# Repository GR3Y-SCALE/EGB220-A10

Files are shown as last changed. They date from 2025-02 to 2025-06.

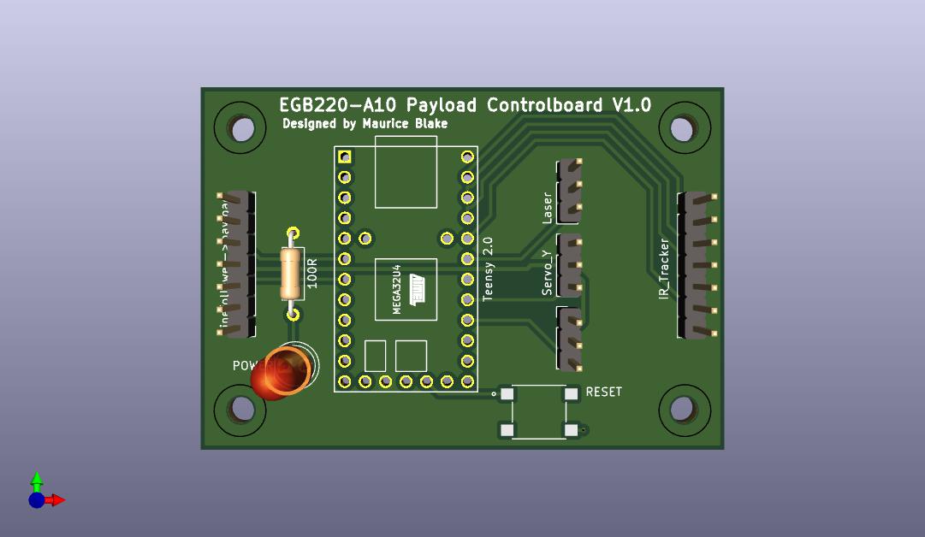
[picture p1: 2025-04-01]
images/PCBs/payload_controlboard_V1.jpg

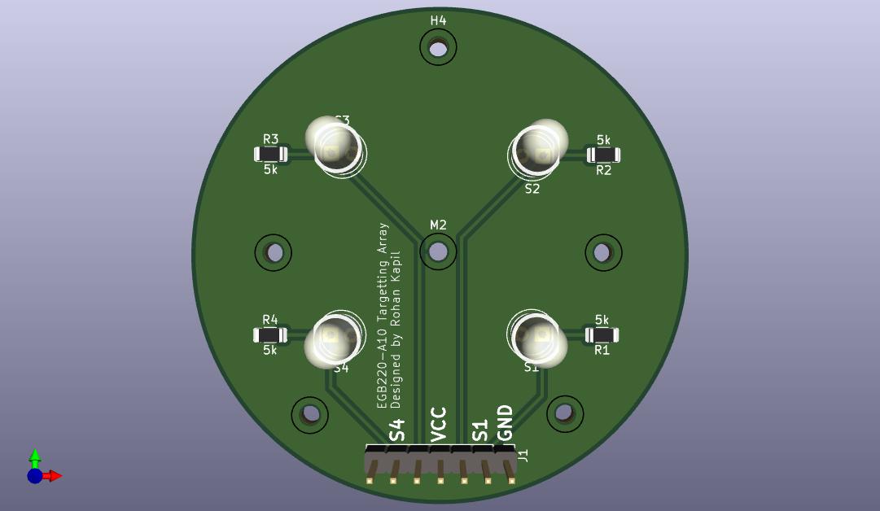
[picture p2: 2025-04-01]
images/PCBs/TargettingPayload.jpg

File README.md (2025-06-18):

# EGB220-A10 - Line follower robot
Robot
General repository for CAD models, PCB design and firmware.

## What is the directory structure?
The initial version of this github repository has several directories that contain relevant readmes similar to this one you are reading right now, they give an example of what goes into that directory.

## Questions?
Feel free to reach out to myself or other the other project members for details and clairifcation.

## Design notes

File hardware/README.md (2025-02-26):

## This directory is for everything related to CAD, such as PCB design and BOMs and 3D models and acrylic cut out files for the line following robot.

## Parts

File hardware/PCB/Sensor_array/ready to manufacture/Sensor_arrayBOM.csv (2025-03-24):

Reference | Value | Datasheet | Footprint | Qty | DNP | DigiKeyPartNumber
C1 | 0.1uF | ~ | Capacitor_SMD:C_0805_2012Metric | 1 |  | 478-KGM21NR71H104KTTR-ND
C2 | 1.0uF | ~ | Capacitor_SMD:C_0805_2012Metric | 1 |  | 1276-1029-2-ND
J2 | 8x2 Sensor Connector | ~ | Connector_PinHeader_2.54mm:PinHeader_2x08_P2.54mm_Vertical | 1
Q1 | BSS214NW | https://www.infineon.com/dgdl/Infineon-BSS214NW-DS-v02_02-en.pdf?fileId=db3a30431b3e89eb011b695aebc01bde | Package_TO_SOT_SMD:SOT-323_SC-70 | 1 |  | QRE1113GRTR-ND
R1,R2,R3,R4,R14,R15 | 47R | ~ | Resistor_SMD:R_0805_2012Metric | 6 |  | RMCF0805JT47R0TR-ND
R5,R6,R7,R8,R9,R10,R11,R12,R13 | 47k | ~ | Resistor_SMD:R_0805_2012Metric | 9 |  | RMCF0805JT47K0TR-ND
U1,U2,U3,U6,U7,U8,U9,U10 | QRE1113GR | http://www.onsemi.com/pub/Collateral/QRE1113-D.PDF | OptoDevice:OnSemi_CASE100CY | 8

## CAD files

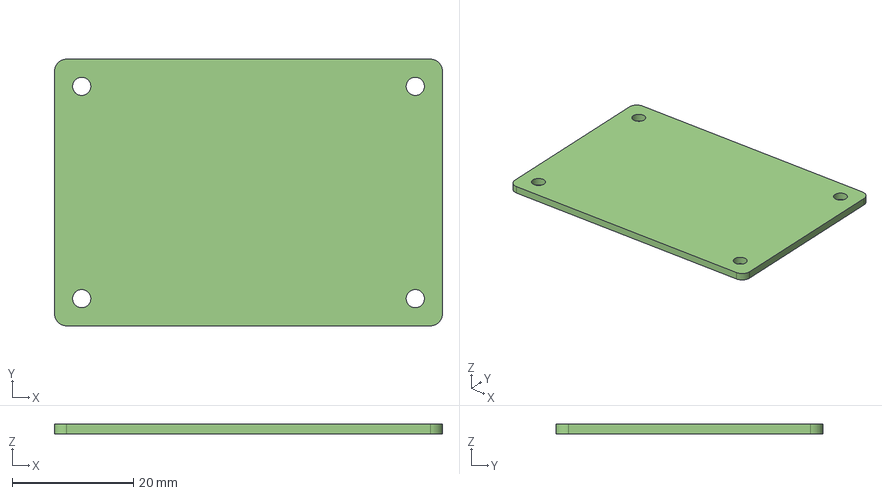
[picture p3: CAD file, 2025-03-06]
hardware/CAD/mvp stage 1/line-follower - mainboard PCB.step
64.0 x 44.0 x 1.60 mm

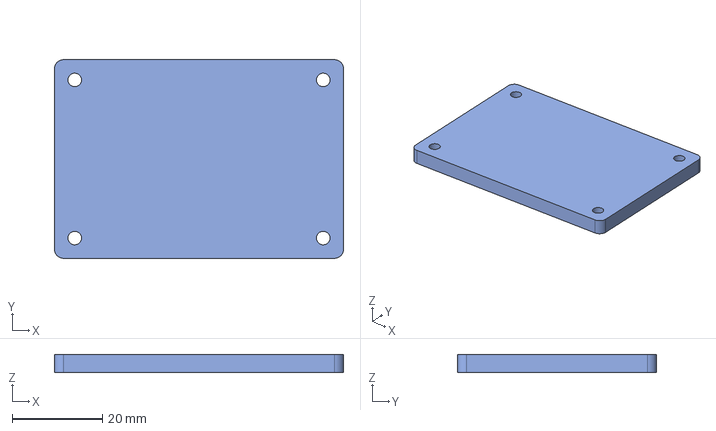
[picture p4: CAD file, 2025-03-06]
hardware/CAD/mvp stage 1/line-follower - PayloadTopPlate.step
64.0 x 44.0 x 4.00 mm

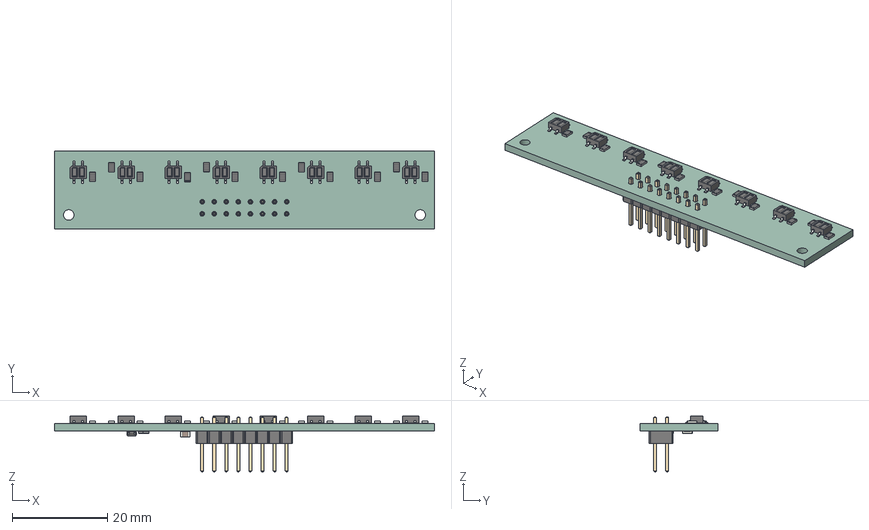
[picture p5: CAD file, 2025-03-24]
hardware/PCB/Sensor_array/ready to manufacture/Sensor_array.step
80.0 x 16.5 x 11.7 mm
R_0805_2012Metric x 15
OnSemi_CASE100CY x 8
C_0805_2012Metric x 2
SOT_323_SC_70
PinHeader_2x08_P254mm_Vertical
_autosave-Sensor_array_PCB

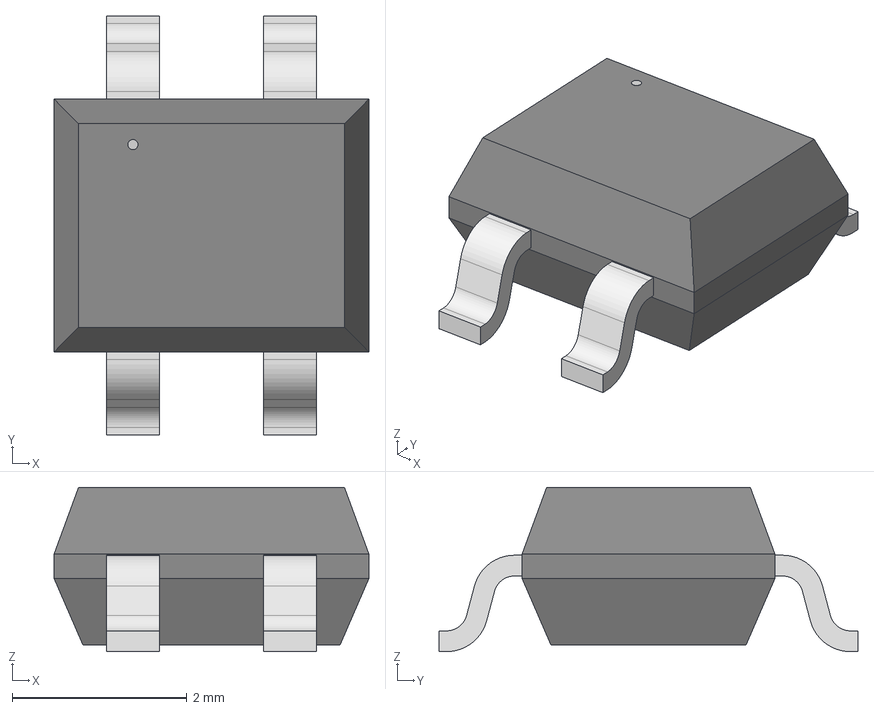
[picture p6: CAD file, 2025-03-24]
hardware/PCB/Sensor_array/reference components/QRE1113GR/ARUSM-313_100CY_FAS.step
3.61 x 4.80 x 1.88 mm

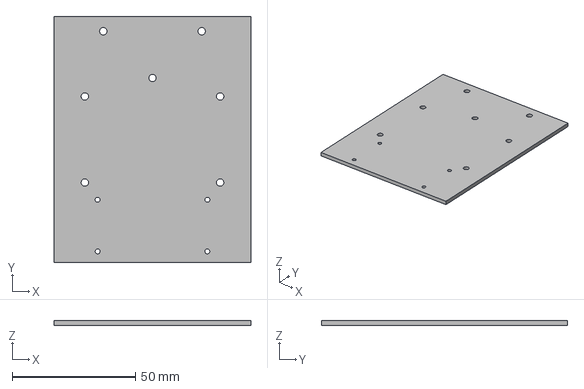
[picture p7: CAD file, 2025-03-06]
hardware/CAD/mvp stage 1/line-follower - chassis.step
80.0 x 100.0 x 2.00 mm

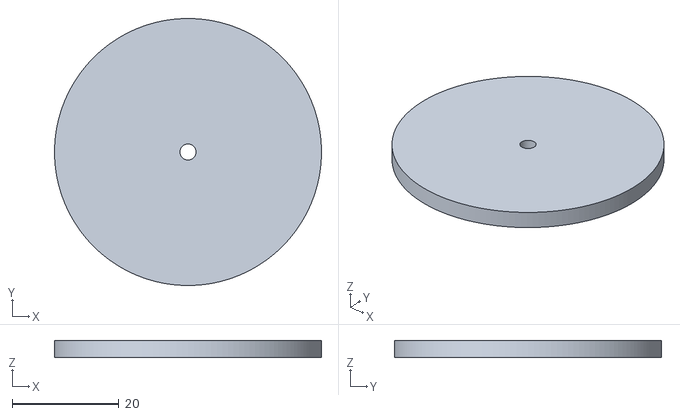
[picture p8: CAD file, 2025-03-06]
hardware/CAD/mvp stage 1/line-follower - skid_spacer.stl
50.0 x 50.0 x 3.22

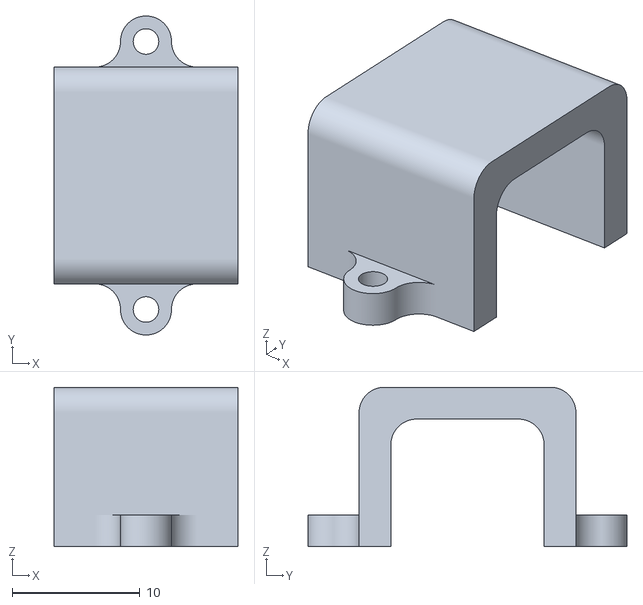
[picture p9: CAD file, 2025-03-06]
hardware/CAD/mvp stage 1/line-follower - motor_mount.stl
14.4 x 25.0 x 12.5

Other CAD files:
hardware/CAD/mvp stage 1/line-follower - chassis.stl

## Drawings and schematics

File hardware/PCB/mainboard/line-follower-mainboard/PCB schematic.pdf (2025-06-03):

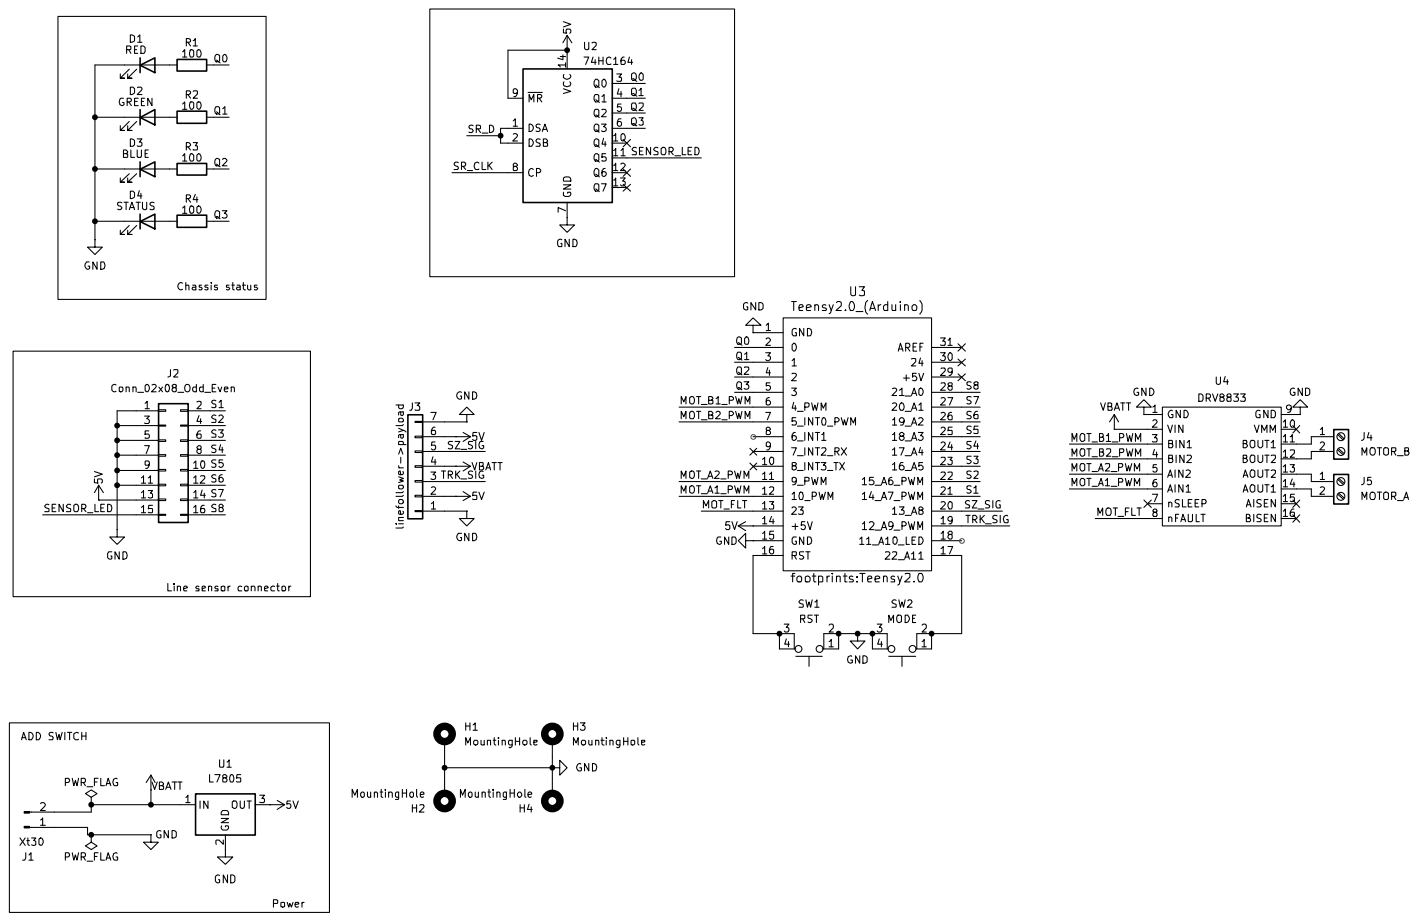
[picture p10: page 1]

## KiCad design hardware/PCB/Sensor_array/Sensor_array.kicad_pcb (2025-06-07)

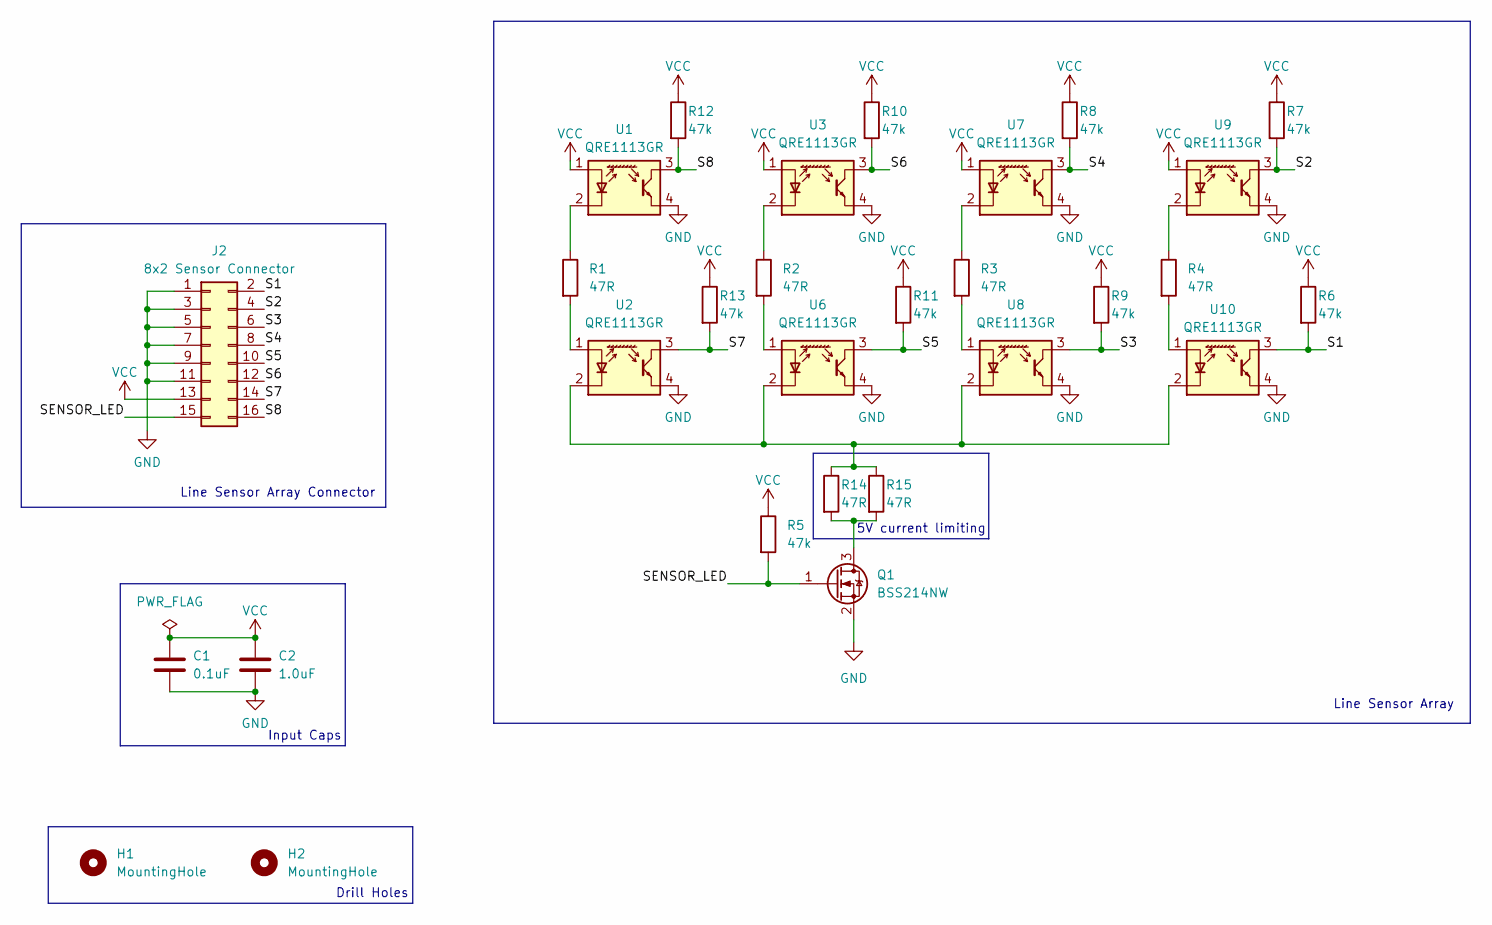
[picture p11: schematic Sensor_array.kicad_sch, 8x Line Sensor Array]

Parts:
C1: 0.1uF; C_0805_2012Metric; DigiKeyPartNumber 478-KGM21NR71H104KTTR-ND
C2: 1.0uF; C_0805_2012Metric; DigiKeyPartNumber 1276-1029-2-ND
H1, H2: MountingHole; MountingHole_2.2mm_M2
J2: 8x2 Sensor Connector; PinHeader_2x08_P2.54mm_Vertical
Q1: BSS214NW; SOT-323_SC-70; DigiKeyPartNumber QRE1113GRTR-ND
R1, R2, R3, R4, R14, R15: 47R; R_0805_2012Metric; DigiKeyPartNumber RMCF0805JT47R0TR-ND
R5, R6, R7, R8, R9, R10, R11, R12, R13: 47k; R_0805_2012Metric; DigiKeyPartNumber RMCF0805JT47K0TR-ND
U1, U2, U3, U6, U7, U8, U9, U10: QRE1113GR; OnSemi_CASE100CY

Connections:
/S1: J2.2, R6.2, U10.3
/S2: J2.4, R7.2, U9.3
/S3: J2.6, R9.2, U8.3
/S4: J2.8, R8.2, U7.3
/S5: J2.10, R11.2, U6.3
/S6: J2.12, R10.2, U3.3
/S7: J2.14, R13.2, U2.3
/S8: J2.16, R12.2, U1.3
/SENSOR_LED: J2.15, Q1.1 (G), R5.2
GND: C1.1, C2.1, J2.1, J2.3, J2.5, J2.7, J2.9, J2.11, Q1.2 (S), U1.4, U2.4, U3.4, U6.4, U7.4, U8.4, U9.4, U10.4
unnamed: Q1.3 (D), R14.2, R15.2
unnamed: R1.1, U1.2 (K)
unnamed: R1.2, U2.1 (A)
unnamed: R2.1, U3.2 (K)
unnamed: R2.2, U6.1 (A)
unnamed: R3.1, U7.2 (K)
unnamed: R3.2, U8.1 (A)
unnamed: R4.1, U9.2 (K)
unnamed: R4.2, U10.1 (A)
unnamed: R14.1, R15.1, U2.2 (K), U6.2 (K), U8.2 (K), U10.2 (K)
VCC: C1.2, C2.2, J2.13, R5.1, R6.1, R7.1, R8.1, R9.1, R10.1, R11.1, R12.1, R13.1, U1.1 (A), U3.1 (A), U7.1 (A), U9.1 (A)

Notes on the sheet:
Input Caps
5V current limiting
Line Sensor Array Connector
Drill Holes
Line Sensor Array

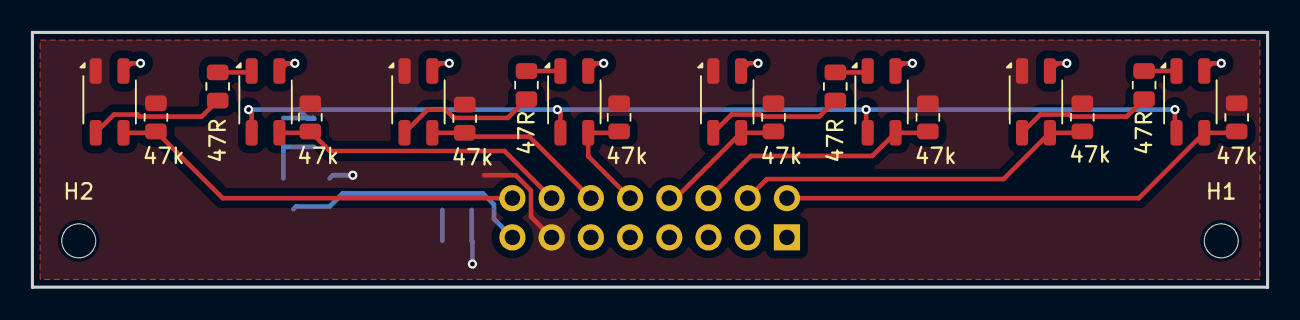
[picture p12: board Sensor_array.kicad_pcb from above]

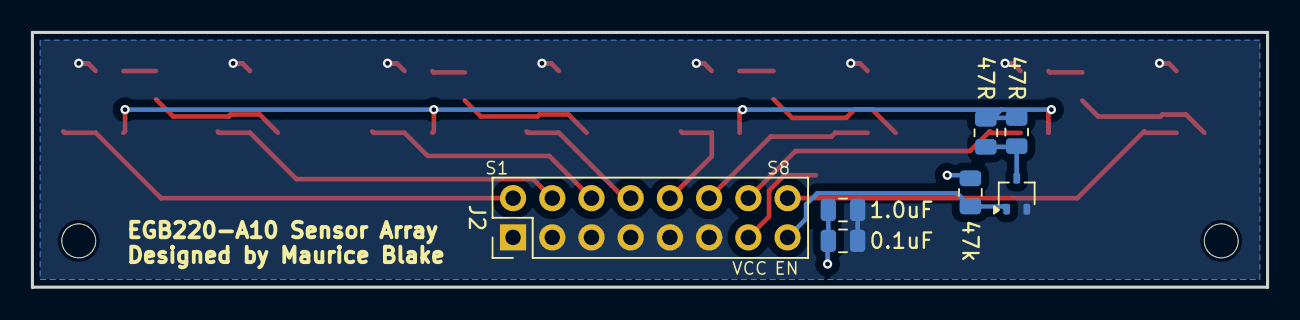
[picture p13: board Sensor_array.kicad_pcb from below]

Board: 2 copper layers, 80.0 x 16.5 mm, 29 parts (7 on the bottom side), 21 nets.

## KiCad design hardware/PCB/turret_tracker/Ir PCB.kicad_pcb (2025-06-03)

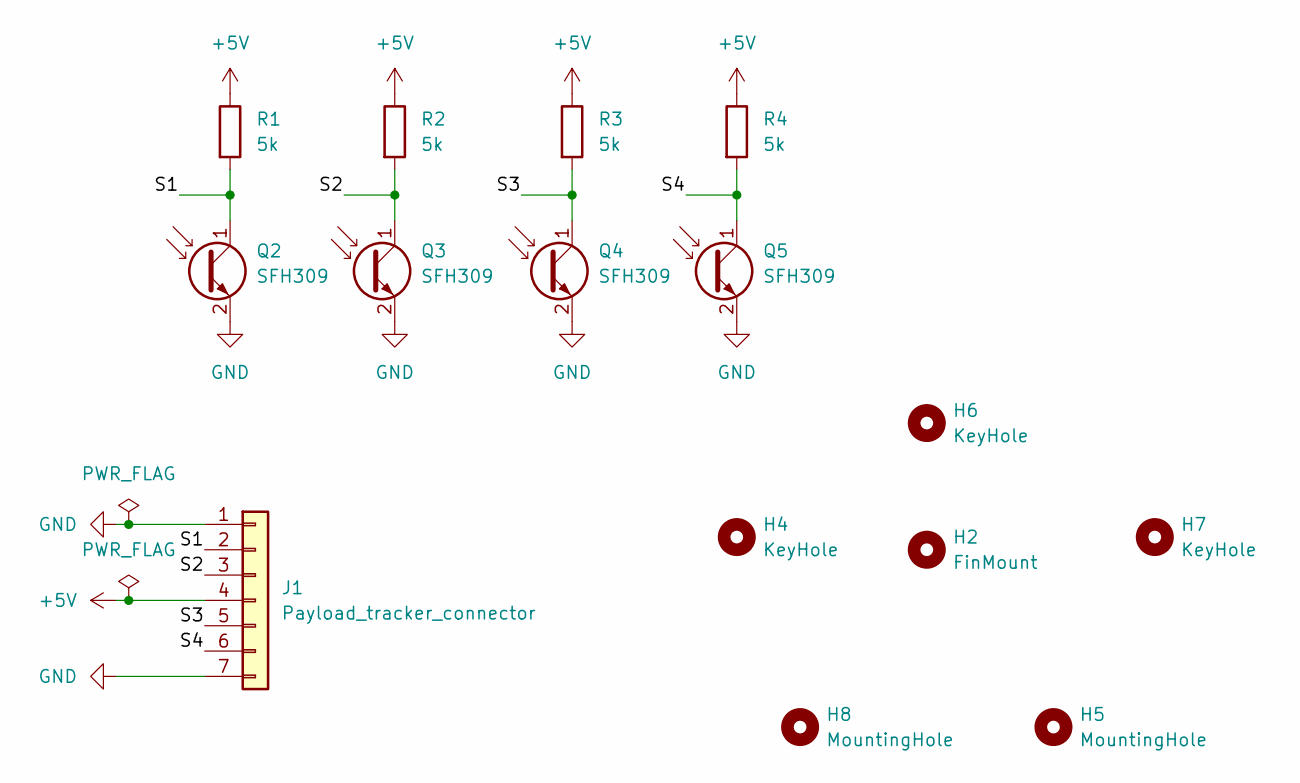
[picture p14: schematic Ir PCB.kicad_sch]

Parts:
H2: FinMount; MountingHole_4.3mm_M4
H4, H6, H7: KeyHole; MountingHole_2.2mm_M2
H5, H8: MountingHole; MountingHole_2.2mm_M2
J1: Payload_tracker_connector; PinHeader_1x07_P2.54mm_Vertical
Q2, Q3, Q4, Q5: SFH309; LED_D5.0mm_Clear
R1, R2, R3, R4: 5k; R_1206_3216Metric

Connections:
+5V: J1.4, R1.1, R2.1, R3.1, R4.1
/S1: J1.2, Q2.1 (C), R1.2
/S2: J1.3, Q3.1 (C), R2.2
/S3: J1.5, Q4.1 (C), R3.2
/S4: J1.6, Q5.1 (C), R4.2
GND: J1.1, J1.7, Q2.2 (E), Q3.2 (E), Q4.2 (E), Q5.2 (E)

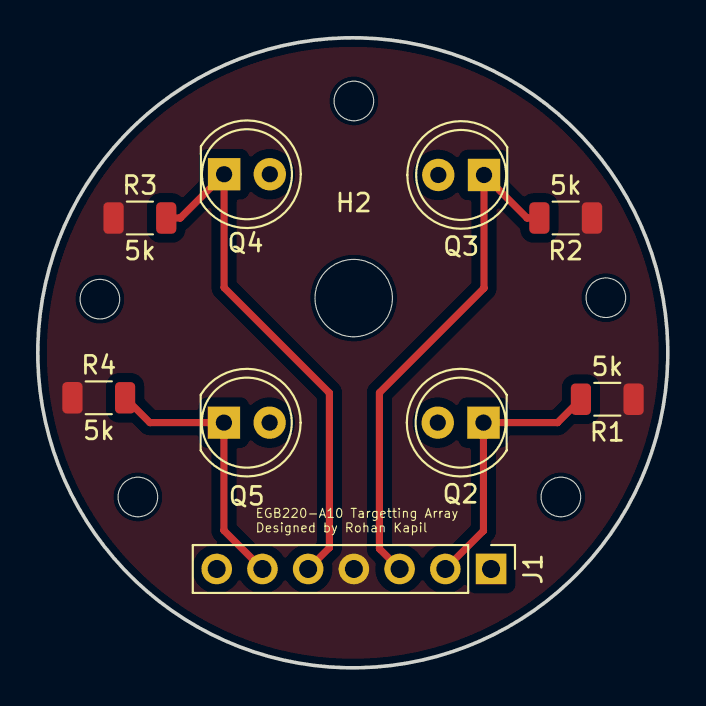
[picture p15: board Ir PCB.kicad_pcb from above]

Board: 2 copper layers, 35.0 x 35.0 mm, 15 parts (0 on the bottom side), 6 nets.

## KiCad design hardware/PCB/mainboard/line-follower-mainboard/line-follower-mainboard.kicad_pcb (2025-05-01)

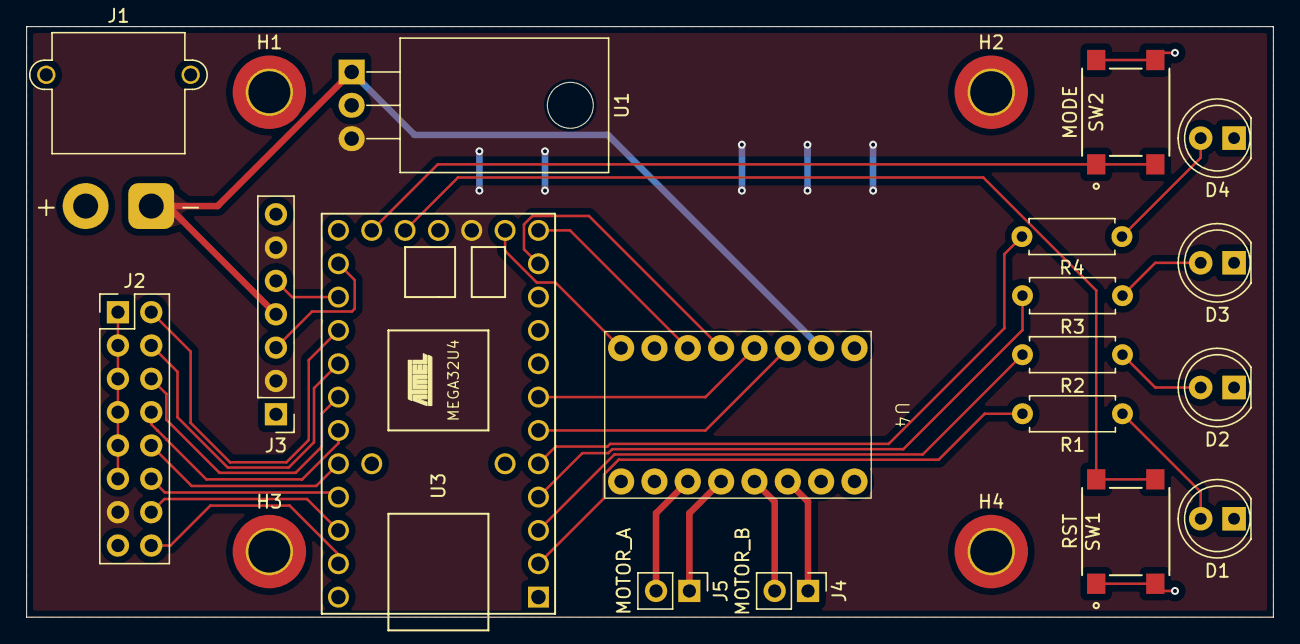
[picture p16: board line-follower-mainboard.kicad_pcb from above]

Board: 2 copper layers, 95.0 x 45.0 mm, 22 parts (0 on the bottom side), 32 nets.

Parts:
D1: RED; LED_D5.0mm
D2: GREEN; LED_D5.0mm
D3: BLUE; LED_D5.0mm
D4: STATUS; LED_D5.0mm
H1, H2, H3, H4: MountingHole; MountingHole_3.2mm_M3_DIN965_Pad_TopBottom
J1: Xt30; AMASS_XT30PW-M_1x02_P2.50mm_Horizontal
J2: Conn_02x08_Odd_Even; PinHeader_2x08_P2.54mm_Vertical
J3: linefollower->payload; PinHeader_1x07_P2.54mm_Vertical
J4: MOTOR_B; PinHeader_1x02_P2.54mm_Vertical
J5: MOTOR_A; PinHeader_1x02_P2.54mm_Vertical
R1, R2, R3, R4: 100; R_Axial_DIN0207_L6.3mm_D2.5mm_P7.62mm_Horizontal
SW1: RST; SO4_222A-M-V-B_CTS
SW2: MODE; SO4_222A-M-V-B_CTS
U1: L7805; TO-220-3_Horizontal_TabDown
U3: Teensy2.0_(Arduino); Teensy2.0
U4: DRV8833

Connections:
5V: J2.13, J3.2, J3.6, U1.3 (OUT), U3.14 (+5V)
/MOT_A1_PWM: U3.12 (10_PWM), U4.6 (AIN1)
/MOT_A2_PWM: U3.11 (9_PWM), U4.5 (AIN2)
/MOT_B1_PWM: U3.6 (4_PWM), U4.3 (BIN1)
/MOT_B2_PWM: U3.7 (5_INT0_PWM), U4.4 (BIN2)
/MOT_FLT: U3.13 (23), U4.8 (nFAULT)
/Q0: R1.2, U3.2 (0)
/Q1: R2.2, U3.3 (1)
/Q2: R3.2, U3.4 (2)
/Q3: R4.2, U3.5 (3)
/S1: J2.2, U3.21 (14_A7_PWM)
/S2: J2.4, U3.22 (15_A6_PWM)
/S3: J2.6, U3.23 (16_A5)
/S4: J2.8, U3.24 (17_A4)
/S5: J2.10, U3.25 (18_A3)
/S6: J2.12, U3.26 (19_A2)
/S7: J2.14, U3.27 (20_A1)
/S8: J2.16, U3.28 (21_A0)
/SZ_SIG: J3.5, U3.20 (13_A8)
/TRK_SIG: J3.3, U3.19 (12_A9_PWM)
GND: D1.1 (K), D2.1 (K), D3.1 (K), D4.1 (K), H1.1, H2.1, H3.1, H4.1, J1.2, J2.1, J2.3, J2.5, J2.7, J2.9, J2.11, J3.1, J3.7, SW1.1, SW1.2, SW2.3 (K), SW2.4 (A), U1.2 (GND), U3.1 (GND), U3.15 (GND), U4.1 (GND), U4.9 (GND)
unnamed: D1.2 (A), R1.1
unnamed: D2.2 (A), R2.1
unnamed: D3.2 (A), R3.1
unnamed: D4.2 (A), R4.1
unnamed: J4.1, U4.11 (BOUT1)
unnamed: J4.2, U4.12 (BOUT2)
unnamed: J5.1, U4.13 (AOUT2)
unnamed: J5.2, U4.14 (AOUT1)
unnamed: SW1.3 (K), SW1.4 (A), U3.16 (RST)
unnamed: SW2.1, SW2.2, U3.17 (22_A11)
VBATT: J1.1, J3.4, U1.1 (IN), U4.2 (VIN)

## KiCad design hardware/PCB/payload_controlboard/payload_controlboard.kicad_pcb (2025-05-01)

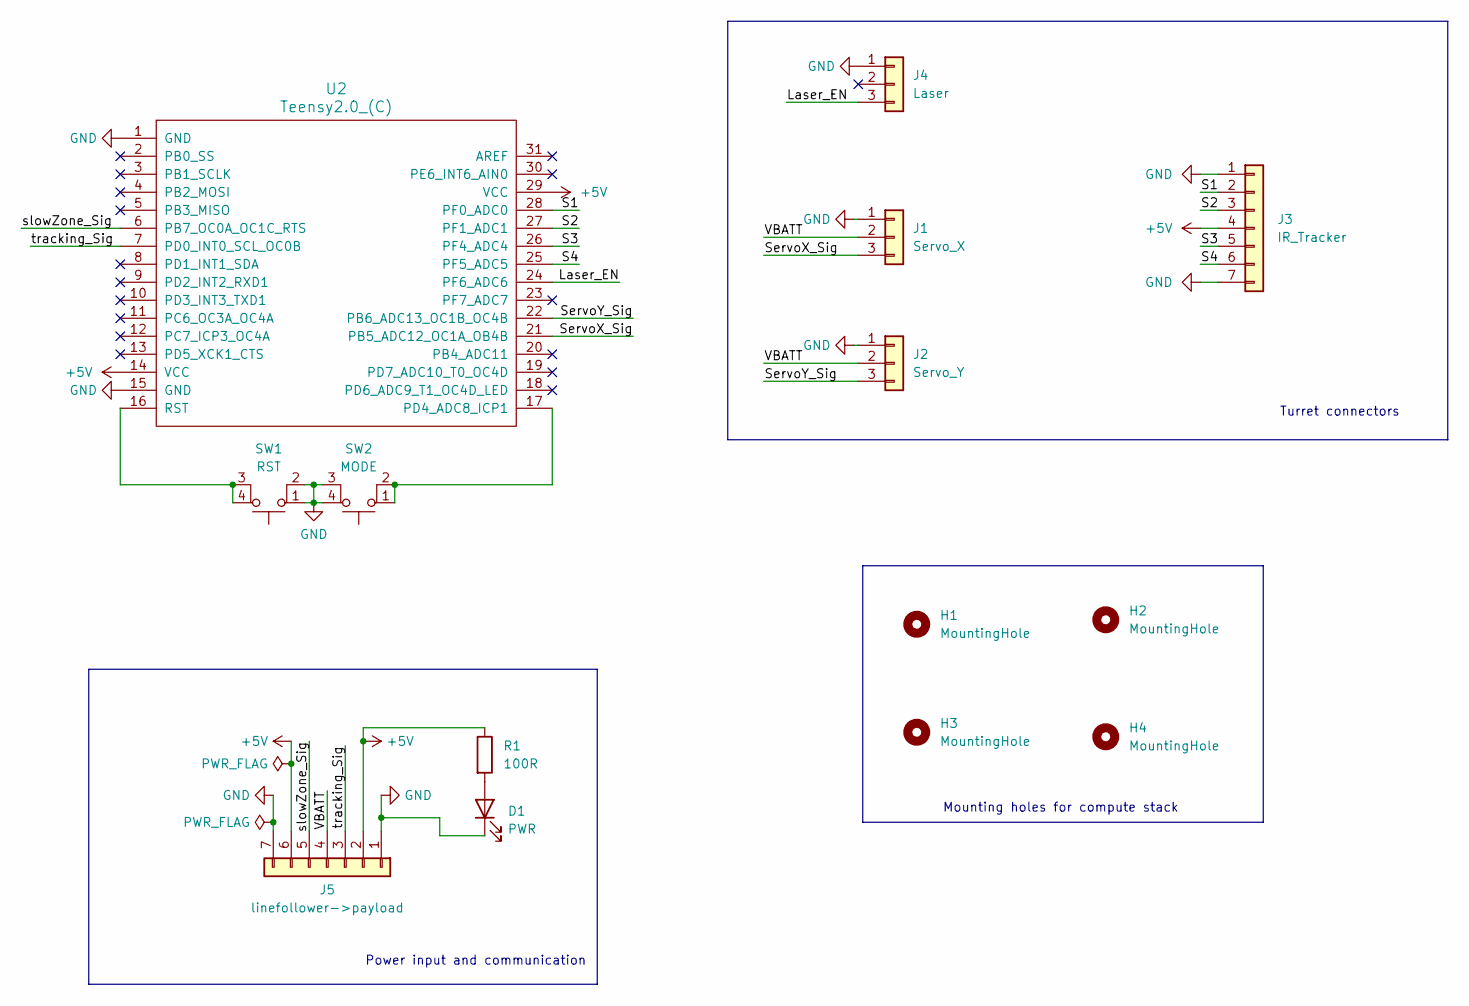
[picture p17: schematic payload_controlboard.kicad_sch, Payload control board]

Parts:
D1: PWR; LED_D5.0mm
H1, H2, H3, H4: MountingHole; MountingHole_3.2mm_M3
J1: Servo_X; PinHeader_1x03_P2.54mm_Vertical
J2: Servo_Y; PinHeader_1x03_P2.54mm_Vertical
J3: IR_Tracker; PinHeader_1x07_P2.54mm_Vertical
J4: Laser; PinHeader_1x03_P2.54mm_Vertical
J5: linefollower->payload; PinHeader_1x07_P2.54mm_Vertical
R1: 100R; R_Axial_DIN0207_L6.3mm_D2.5mm_P10.16mm_Horizontal
SW1: RST; SO4_222A-M-V-B_CTS
SW2: MODE; SO4_222A-M-V-B_CTS
U2: Teensy2.0_(C); Teensy2.0

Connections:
+5V: J3.4, J5.2, J5.6, R1.1, U2.14 (VCC), U2.29 (VCC)
/Laser_EN: J4.3, U2.24 (PF6_ADC6)
/S1: J3.2, U2.28 (PF0_ADC0)
/S2: J3.3, U2.27 (PF1_ADC1)
/S3: J3.5, U2.26 (PF4_ADC4)
/S4: J3.6, U2.25 (PF5_ADC5)
/ServoX_Sig: J1.3, U2.21 (PB5_ADC12_OC1A_OB4B)
/ServoY_Sig: J2.3, U2.22 (PB6_ADC13_OC1B_OC4B)
/VBATT: J1.2, J2.2, J5.4
/slowZone_Sig: J5.5, U2.6 (PB7_OC0A_OC1C_RTS)
/tracking_Sig: J5.3, U2.7 (PD0_INT0_SCL_OC0B)
GND: D1.1 (K), J1.1, J2.1, J3.1, J3.7, J4.1, J5.1, J5.7, SW1.1, SW1.2, SW2.3 (K), SW2.4 (A), U2.1 (GND), U2.15 (GND)
unnamed: D1.2 (A), R1.2
unnamed: SW1.3 (K), SW1.4 (A), U2.16 (RST)
unnamed: SW2.1, SW2.2, U2.17 (PD4_ADC8_ICP1)

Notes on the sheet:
Power input and communication
Mounting holes for compute stack
Turret connectors

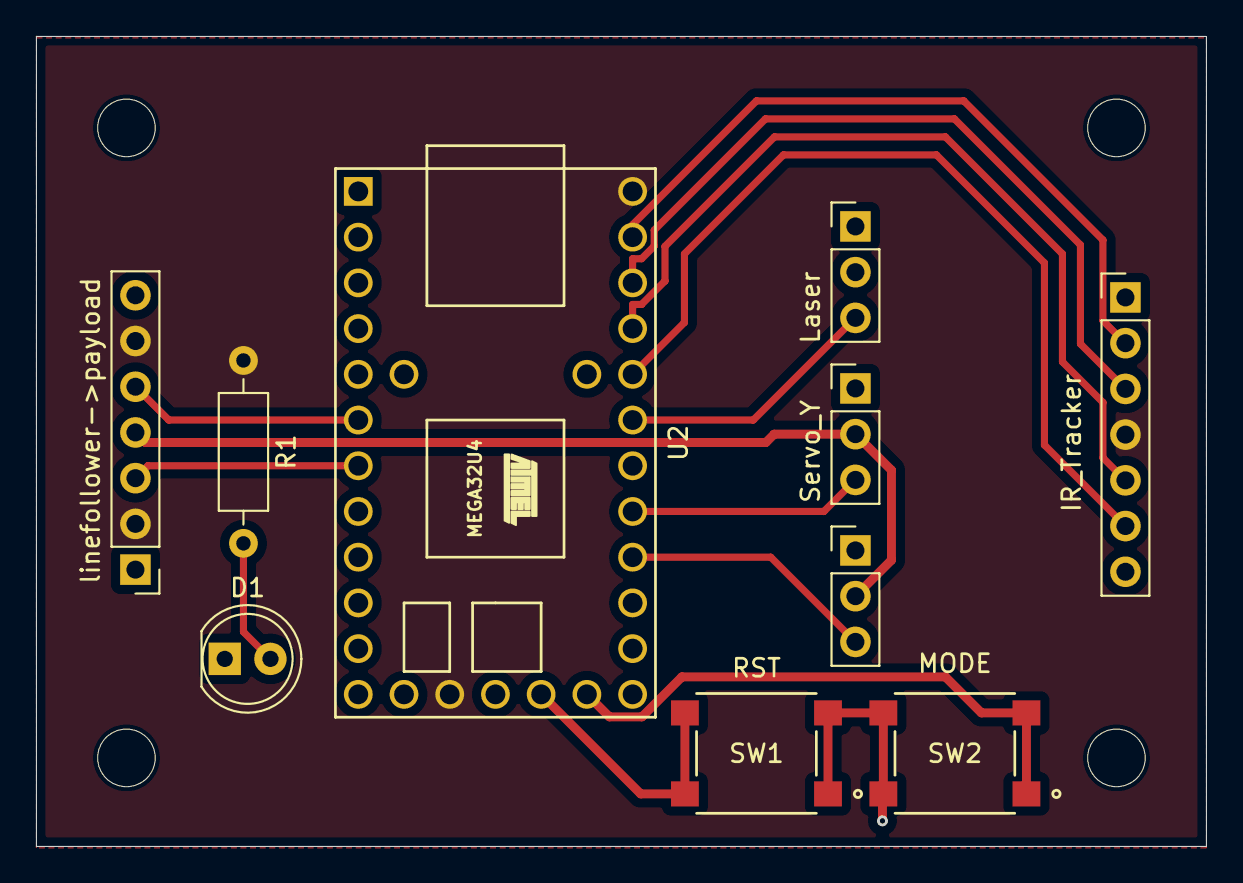
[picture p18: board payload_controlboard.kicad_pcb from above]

Board: 2 copper layers, 65.0 x 45.0 mm, 14 parts (0 on the bottom side), 15 nets.

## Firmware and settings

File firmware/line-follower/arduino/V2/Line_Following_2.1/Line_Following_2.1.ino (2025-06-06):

#include "PIDMotorControl.h"

// Define sensor pins(from Right to Left) using #define
#define s1 A3
#define s2 A2
#define s3 A1
#define s4 A0
#define s5 A8
#define s6 A7
#define s7 A11
#define s8 A6

// Motor Pins
#define motorLeftDir 7      // Direction pin for left motor
#define motorLeftPWM 3      // PWM pin for left motor speed
#define motorRightDir 17     // Direction pin for right motor
#define motorRightPWM 11    // PWM pin for right motor speed

void setup() {
  // Initialize IR sensor pins as INPUT
  pinMode(s1, INPUT);
  pinMode(s2, INPUT);
  pinMode(s3, INPUT);
  pinMode(s4, INPUT);
  pinMode(s5, INPUT);
  pinMode(s6, INPUT);
  pinMode(s7, INPUT);
  pinMode(s8, INPUT);
  
  // Initialize Left and Right Motor 
  pinMode(motorLeftDir, OUTPUT);
  pinMode(motorLeftPWM, OUTPUT);
  pinMode(motorRightDir, OUTPUT);
  pinMode(motorRightPWM, OUTPUT);

  Serial.begin(9600);  // Start serial communication for debugging
}

void loop() {
  // Obtain sensor reading
  int sValues[8];  // Create an array to store the sensor readings
  readsensors(sValues);  // Pass the array to the readsensors function

  // Print sensor readings
  for (int i = 0; i < 8; i++) {
    Serial.print("S ");
    Serial.print(i + 1);  // Display sensor number (1 to 8)
    Serial.print(": ");
    Serial.println(sValues[i]);
  }

  // Calculate error based on the sensor readings
  int error = calculateError(sValues);

  // Print the error for debugging
  Serial.print("Error: ");
  Serial.println(error);

  // Apply PID control to adjust motor speeds
  PIDMotorControl(error);

  delay(50);  // Short delay for smooth motor control
}


void readsensors(int sValues[]){
  // Read values from the IR sensors using defined pin names and store them to sValues[]
  sValues[0] = analogRead(s1);
  sValues[1] = analogRead(s2);
  sValues[2] = analogRead(s3);
  sValues[3] = analogRead(s4);
  sValues[4] = analogRead(s5);
  sValues[5] = analogRead(s6);
  sValues[6] = analogRead(s7);
  sValues[7] = analogRead(s8);
}


// int calculateError(int sValues[]) {
//   int error = 0;
//   int threshold = 100;  // Adjust threshold based on sensor calibration

//   // Check if center sensors (4th and 5th) are detecting the white line
//   if (sValues[3] < threshold && sValues[4] < threshold) {
//     error = 0;  // Both 4th and 5th sensors are on the white line (center)
//   } else {
//     // Check left side sensors (s1, s2, s3)
//     for (int i = 0; i < 3; i++) {
//       if (sValues[i] < threshold) {
//         // The error is proportional to the distance from the center
//         error = - (3 - i);  // Largest error for s1, smallest for s3
//         break;
//       }
//     }
    
//     // Check right side sensors (6th, 7th, 8th)
//     for (int i = 7; i > 4; i--) {
//       if (sValues[i] < threshold) {
//         // The error is proportional to the distance from the center
//         error = (i - 4);  // Largest error for s8 (i=7), smallest for s6 (i=5)
//         break;
//       }
//     }
//   }

//   return error;
// }

// void PIDMotorControl(int error) {
//   // Calculate PID terms
//   float derivative = error - previousError;
//   integral += error;

//   // Calculate the PID output (adjust the formula for your application)
//   float output = Kp * error + Ki * integral + Kd * derivative;

//   // Limit the output to a max value (to prevent overshooting)
//   if (output > 255) output = 255;
//   if (output < -255) output = -255;

//   // Print the PID output for debugging
//   Serial.print("PID Output: ");
//   Serial.println(output);

//   // Motor control logic based on PID output
//   int motorSpeed = 180;  // Base motor speed (you can adjust this)

//   // Apply PID correction to the motors
//   int leftMotorSpeed = motorSpeed - output;  
//   int rightMotorSpeed = motorSpeed + output;

//   // Ensure motor speeds are within PWM range (0-255)
//   if (leftMotorSpeed < 0) leftMotorSpeed = 0;
//   if (leftMotorSpeed > 255) leftMotorSpeed = 255;

//   if (rightMotorSpeed < 0) rightMotorSpeed = 0;
//   if (rightMotorSpeed > 255) rightMotorSpeed = 255;

//   // Set the motor speeds (same direction for both motors)
//   digitalWrite(motorLeftDir, HIGH);  // Left motor forward
//   analogWrite(motorLeftPWM, leftMotorSpeed);  // Set left motor speed

//   digitalWrite(motorRightDir, HIGH);  // Right motor forward
//   analogWrite(motorRightPWM, rightMotorSpeed);  // Set right motor speed

//   // Update the previous error for the next loop
//   previousError = error;
// }

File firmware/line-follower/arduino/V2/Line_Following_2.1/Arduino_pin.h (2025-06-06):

#ifdef SPARK
    // Define sensor pins(from Right to Left) using #define
    #define s1 A7
    #define s2 A6
    #define s3 A5
    #define s4 A4
    #define s5 A3
    #define s6 A2
    #define s7 A1
    #define s8 A0

    //Define Left Right Marker Sensor
    #define sL A4   //reconfig pin during tuning
    #define sR A5   //reconfig pin during tuning

    //Define Red, Green, Blue LED
    #define RLED 0
    #define GLED 1
    #define BLED 2
    #define BUILTIN_LED 11

    // Motor Pins
    //#define motorLeftDir 7      // Direction pin for left motor
    #define motorLeftPWM 9     // PWM pin for left motor speed
    //#define motorRightDir 17     // Direction pin for right motor
    #define motorRightPWM 4    // PWM pin for right motor speed

    //Define Push Button
    #define StartButton 22

    //Define Payload System Pin
    #define SZ_SIG 13
    #define TRK_SIG 12
#endif 

#ifdef TEENSY

    // Define sensor pins(from Right to Left) using #define
    #define s1 14
    #define s2 15
    #define s3 16
    #define s4 17
    #define s5 18
    #define s6 19
    #define s7 20
    #define s8 21

    //Define Left Right Marker Sensor
    #define sR 0   //reconfig pin during tuning
    // #define sR A5   //reconfig pin during tuning

    //Define Red, Green, Blue LED
    #define RLED 1
    #define GLED 2
    #define BLED 3
    #define BUILTIN_LED 11

    // Motor Pins
    #define motorLeftA 4      // Direction pin for left motor
    #define motorLeftB 5     // PWM pin for left motor speed
    #define motorRightA 9     // Direction pin for right motor
    #define motorRightB 10    // PWM pin for right motor speed

    //Define Push Button
    #define StartButton 22

    //Define Payload System Pin
    #define SZ_SIG 13
    #define TRK_SIG 12

#endif

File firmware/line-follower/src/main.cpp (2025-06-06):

#include <Arduino.h>

#include <Arduino_pin.h>
#include <readsensors.h>
#include <calculateError.h>
#include <motorControl.h>
#include <detectMarker.h>

//Sensors reading storage
int sValues[8];
int mValues[2];

bool SZ = false; //true when red is detected, false when green is detected
bool SSDetected = false; //true when start stop marker detected
bool SSMarker = false; //true when passed start marker, false when in startstop zone
bool CURVED = false; //True when turning, false when not.

const int sensorPins[] = {s1, s2, s3, s4, s5, s6, s7, s8};

int error = 0;
int lap = 0; 

int motorSpeed = 50;

const int motorTopSpeed = 120;

enum State {
  DEBUG,
  IDLE,
  STRAIGHT,
  TURNING,
  SLOW_ZONE,
  STOPPING,
  STOPPED
};

#ifdef DEBUGGING // Checks for debugging flag
State currentState = DEBUG;
#else
State currentState = IDLE;
#endif

void readsensors(void){
    // Read values from the IR sensors using defined pin names and store them to sValues[]
    for(int i = 0; i < 8; i++){
      sValues[i] = analogRead(sensorPins[i]);
    }
  }

void setup() {
  // Initialize IR sensor pins as INPUT
  pinMode(s1, INPUT);
  pinMode(s2, INPUT);
  pinMode(s3, INPUT);
  pinMode(s4, INPUT);
  pinMode(s5, INPUT);
  pinMode(s6, INPUT);
  pinMode(s7, INPUT);
  pinMode(s8, INPUT);

  //Initialize Left Right Marker Sensors
  //pinMode(sL, INPUT);
  pinMode(sR, INPUT); // Unused

  //Initialize LEDS
  pinMode(RLED, OUTPUT);
  pinMode(BLED, OUTPUT);
  pinMode(GLED, OUTPUT);

  //initialize push button 
  pinMode(StartButton, INPUT);
  
  // Initialize Left and Right Motor 
  pinMode(motorLeftA, OUTPUT);
  pinMode(motorLeftB, OUTPUT);
  pinMode(motorRightA, OUTPUT);
  pinMode(motorRightB, OUTPUT);

  // Initialize Payload Pins
  pinMode(SZ_SIG, OUTPUT);
  pinMode(TRK_SIG, INPUT);

  Serial.begin(9600);  // Start serial communication for debugging
}


void loop() {
  //Read line sensor and side sensors
  readsensors();
  detectMarker();
  
  //Check states
  SZDetector(); //Change SZ state if entering or leaving SZ
  SSDetector(); //Change SS state if crossing starting or finishing line
  CURDetector(); //Change CURVED state if entering and leaving a curve


  switch (currentState){
    case DEBUG: // Test follower mainboard to payload mainboard communications, servo operation and wheel motion
      Serial.println("State: DEBUG");
      delay(1000);
      // Test Slow Zone signal
      Serial.println("TESTING SZ SIGNAL");
      for (int i = 0; i < 5; i++) {
        digitalWrite(SZ_SIG, HIGH);
        Serial.print("...ON");
        delay(500);
        digitalWrite(SZ_SIG, LOW);
        Serial.print("...OFF");
        delay(500);
      }
      Serial.println("...DONE!");
      delay(5000);

      Serial.println("TESTING TRK SIGNAL");
      pinMode(TRK_SIG,OUTPUT);
      for (int i = 0; i < 5; i++) {
        digitalWrite(TRK_SIG, HIGH);
        Serial.print("...ON");
        delay(500);
        digitalWrite(TRK_SIG, LOW);
        Serial.print("...OFF");
        delay(500);
      }
      Serial.println("...DONE!");
      digitalWrite(BUILTIN_LED, HIGH); 
      
    case IDLE:
      Serial.println("State: IDLE");
      digitalWrite(RLED,HIGH); //red led on

      if(analogRead(StartButton)){           //if button is pressed
      digitalWrite(RLED,LOW);//red led off
      motorSpeed = 50;
      currentState = STRAIGHT;
      }
      break;
    
    case STRAIGHT:
      Serial.println("State: STRAIGHT");

      digitalWrite(GLED,HIGH); //green led on
      error = calculateError(sValues);
      PIDMotorControl(error);
      delay(1);

      motorSpeed += 5;
      if (motorSpeed > motorTopSpeed) motorSpeed = motorTopSpeed;

      if(SZ){
        digitalWrite(GLED,LOW);//turn green led off
        currentState = SLOW_ZONE;
      }

      if(SSDetected && !SSMarker){
        digitalWrite(GLED,LOW);//turn green led off
        currentState = STOPPING;
      }

      if(CURVED){
        digitalWrite(GLED,LOW);//turn green led off
        currentState = TURNING;
      }
      break;

    case TURNING:
      Serial.println("State: TURNING");

      motorSpeed = 50;
      error = calculateError(sValues);
      PIDMotorControl(error);

      if(!CURVED){
        currentState = STRAIGHT;
      }
      break;

    case SLOW_ZONE:
      Serial.println("State: SLOW_ZONE");
      
      digitalWrite(SZ_SIG, HIGH); //send high to payload pin

      motorSpeed = 25;
      error = calculateError(sValues);
      PIDMotorControl(error);  

      digitalWrite(GLED,HIGH);//turn on green led for light following
      
      //if log bumper switch is high
      digitalWrite(BLED,HIGH);//if in contact with obs, turn blue led on
      // else
      digitalWrite(BLED, LOW);

      if(digitalRead(TRK_SIG)){
        //digitalWrite(YLED,HIGH); Yellow LED on when tracking
      }
      else{
        //digitalWrite(YLED,LOW);
      }

      if(!SZ){
        digitalWrite(SZ_SIG, LOW);  //send low to payload pin
        digitalWrite(GLED,LOW);
        currentState = STRAIGHT;
        motorSpeed = 50;
      }
      break;

    case STOPPING:
      Serial.print("State: STOPPING");

      digitalWrite(RLED,HIGH);//turn red led on

      motorSpeed -= 5;
      if (motorSpeed<0){
        motorSpeed = 0; 
        currentState = STOPPED;
      }

      error = calculateError(sValues);
      PIDMotorControl(error);
      break;

    case STOPPED:
     Serial.print("State: STOPPED");

     stopMotors();

     delay (2500);

     if(lap<3){
      digitalWrite(RLED,LOW);//red led off
      currentState = STRAIGHT;
      motorSpeed = 50;
      error = 0;
     }
     else{
      currentState = IDLE;
      lap = 0;
     }

     break;

  }
}

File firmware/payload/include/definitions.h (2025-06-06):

// #include <Arduino.h>
// #include <Servo.h>

#define S1 21
#define S2 20
#define S3 19
#define S4 18
#define LASER_EN PIN_F6
#define SZ_SIG PIN_B7
#define TRK_SIG PIN_D0
#define CAL_BTN 22
#define YELLOW PIN_B1
#define GREEN PIN_B0

// /* SENSOR CONFIGURATION
//    _________________
//   /      |  |       \
//  /  [S3] |  |  [S2]  \
// |________|  |_________|
// |________|  |_________|
// |        |  |         |
//  \  [S4] |  |  [S1]  /
//   \______|__|_______/

// */

// Servo servoX;
// Servo servoY;
// const int8_t IRSENSORS[4] = {S2,S3,S1,S4}; // Order of IR sensors on the PCB
// const int8_t numSensors = 4;

// int sensorCalibration[numSensors] = {1000,1000,1000,};
// const int detectionThreshold = 20; // 20 5mV increments, therefore 100mV threshold

// int8_t servoXRestPos = 90;
// int8_t servoYRestPos = 90;

// // Function definitions
// void calibrateSensors();
// bool readSensor(int8_t i);
// bool targetAcquired();
// void scanServoX();

// const int8_t sensor_dx[numSensors] = {-1,1,-1,1};
// const int8_t sensor_dy[numSensors] = {1,1,-1,-1};

// bool TRK = false;
// bool laser_state = false;

// // Tracking binary thresholding definitions
// int8_t dx = 0;
// int8_t dy = 0;

// int8_t norm_dy;
// int8_t norm_dx;

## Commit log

2025-02-26 Added PCB dir and kicad project
    [line-follower.kicad_pcb, line-follower.kicad_sch]
2025-03-04 Added kicad schematic
    [line-follower-mainboard.kicad_pcb, line-follower-mainboard.kicad_sch, line-follower.kicad_pcb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]
2025-03-06 Added minimal viable product stage 1 reference CAD files
    [line-follower - PayloadTopPlate.step, line-follower - chassis.step, line-follower - chassis.stl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]
2025-03-19 Chassis PCB schematic initial layout
    [line-follower-mainboard.kicad_sch]
2025-03-20 added init code
    [Sensor_array.kicad_pcb, Sensor_array.kicad_sch]
2025-03-24 Created prototype sensor array schematic and PCB, revised mainboard
    [ARUSM-313_100CY_FAS.step, SensorArrayV1BOM.csv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]
2025-03-24 Flipped connector and added insightful silkscreen to sensor array
    [Sensor_array-B_Cu.gbr, Sensor_array-B_Mask.gbr, Sensor_array-B_Paste.gbr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]
2025-03-24 added teensy 2.0 symbol for payload subsystem
    [payload_controlboard.kicad_pcb, payload_controlboard.kicad_sch]
2025-03-24 added init schematic
    [payload_controlboard.kicad_sch]
2025-03-29 Initial payload control board and connector layout
    [Sensor_array-B_Cu.gbr, Sensor_array-B_Mask.gbr, Sensor_array-B_Paste.gbr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]
2025-03-30 Added payload connectors and follower->payload compliant connector
    [payload_controlboard.kicad_sch]
2025-04-01 Switched line follower code to PlatformIO
2025-04-01 Finished PCBs for payload and turret
    [Ir PCB-B_Cu.gbr, Ir PCB-B_Mask.gbr, Ir PCB-B_Paste.gbr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]
2025-04-03 Added gitignore to ignore cache files for mac and kicad
2025-04-03 Initial tracking code with calibration, no hysteresis atm
2025-04-03 fixed IR Sensor order, 3,2,4,1 instead of 1,2,3,4
    [main.cpp]
2025-04-05 reversed sensor order, 8->1 instead 1->8
    [main.cpp]
2025-04-05 Fixed logic of sensor detection
    [main.cpp]
2025-04-07 tweaked PID values and threshold, now running code
2025-04-08 kicad backup
2025-05-01 payload v2
    [line-follower-mainboard.kicad_sch, payload_controlboard.kicad_pcb, payload_controlboard.kicad_sch]
2025-05-01 finalised mainboard design
    [line-follower-mainboard.kicad_sch, payload_controlboard.kicad_pcb]
2025-05-14 Jack's Attempt at LED code
2025-05-14 with led code
2025-05-31 Code clean up, debug state added, state machine for payload added
    [Ir PCB-B_Cu.gbr, Ir PCB-B_Mask.gbr, Ir PCB-B_Paste.gbr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]
2025-06-06 Working final demo code and fixes
    [Arduino_pin.h, Line_Following_2.1.ino, PIDMotorControl.ino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]
2025-06-07 Final project commit
    [Sensor_array.kicad_pcb, line-follower-mainboard.kicad_sch]
